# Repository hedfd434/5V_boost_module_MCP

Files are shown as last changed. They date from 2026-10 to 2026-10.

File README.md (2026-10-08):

# 5V converter evaluation board (MCP1640T-I/CHY)
this board allows user to get 5V power supply with maximum out current of 1A (limited by coil to 0.8A).
You can safely power your 5V devices controlled by MCU's or evaluation boards

<figure>
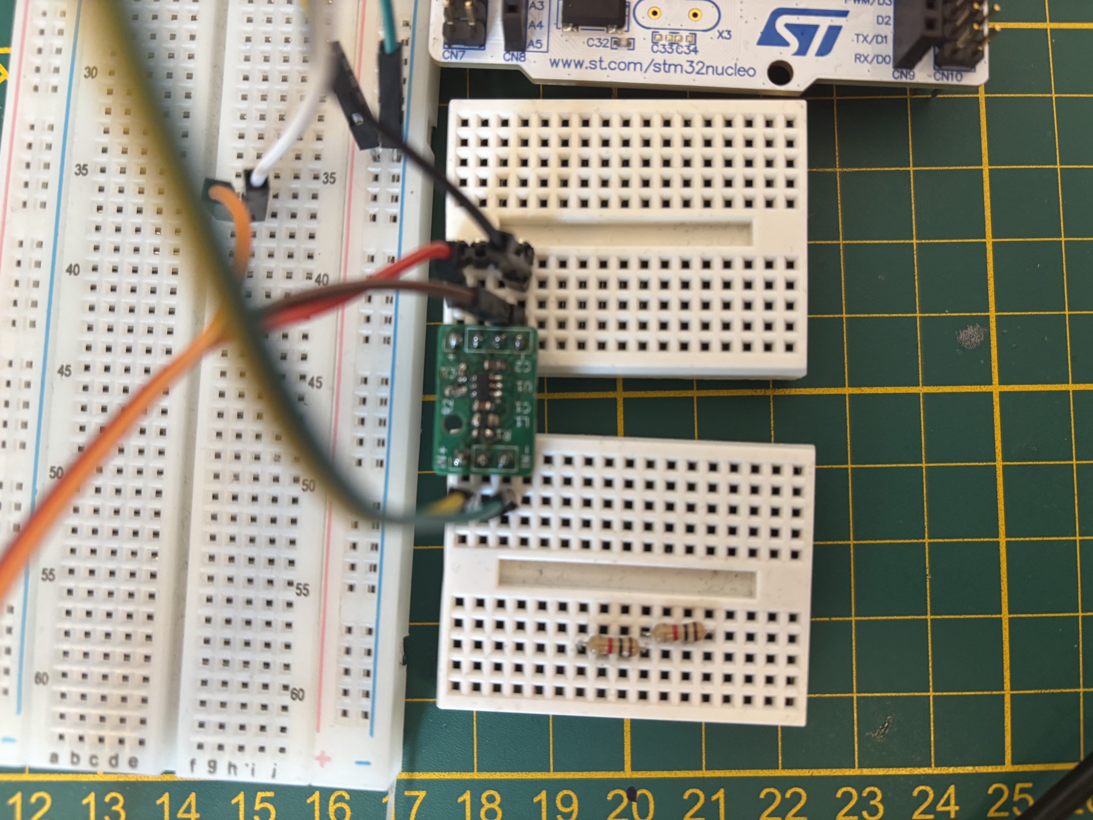
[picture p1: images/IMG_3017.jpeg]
  
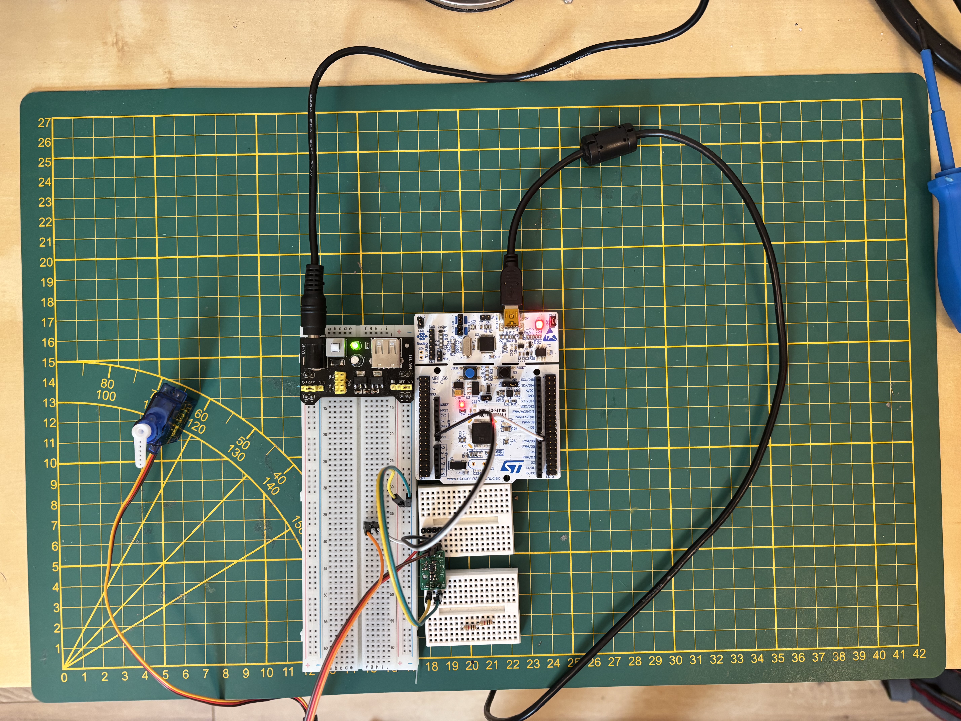
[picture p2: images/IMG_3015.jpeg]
    
  <figcaption>
    Image 1 and 2. Board in real usage power 5V servo
  </figcaption>
</figure>

## features
- DC to DC power conversion (boost)
- input voltage 3.0 to 4.2 V (possible change to range of 0.9 to 1.7V by replacing 309ohm resistor with 562ohm resistor)
- up to 95% efficiency in range of 10 - 100mA
- custom enabler: you can control on and off state by EN pin or permanently solder the 0ohm resistor.

<figure>
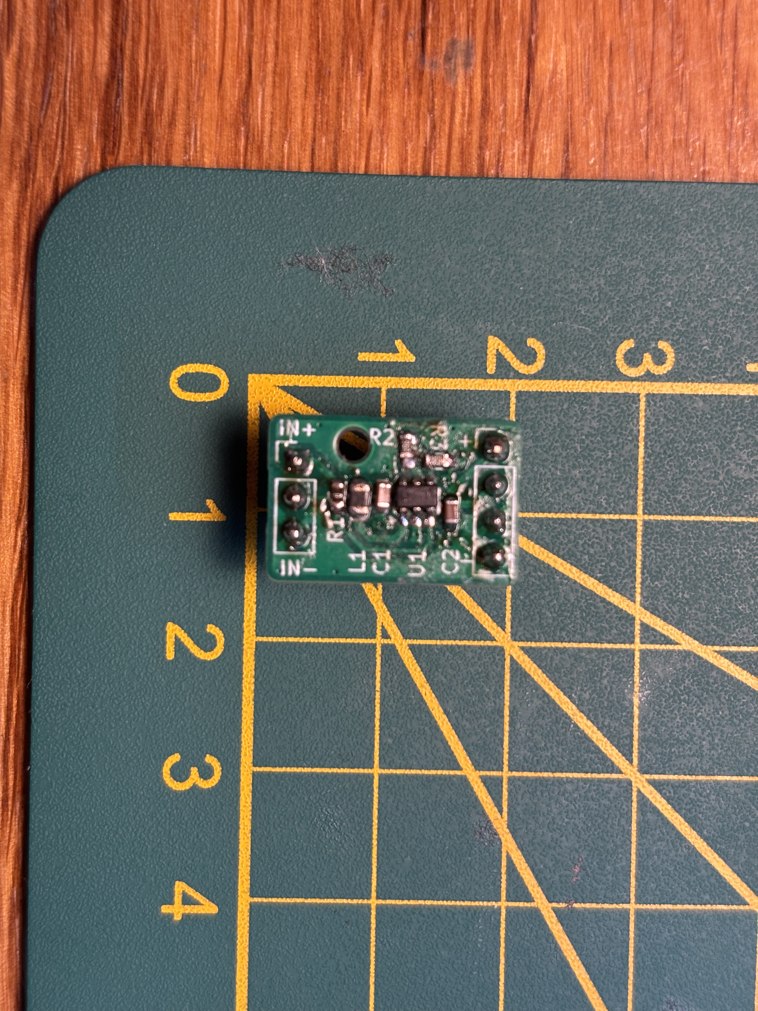
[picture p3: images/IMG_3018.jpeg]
  
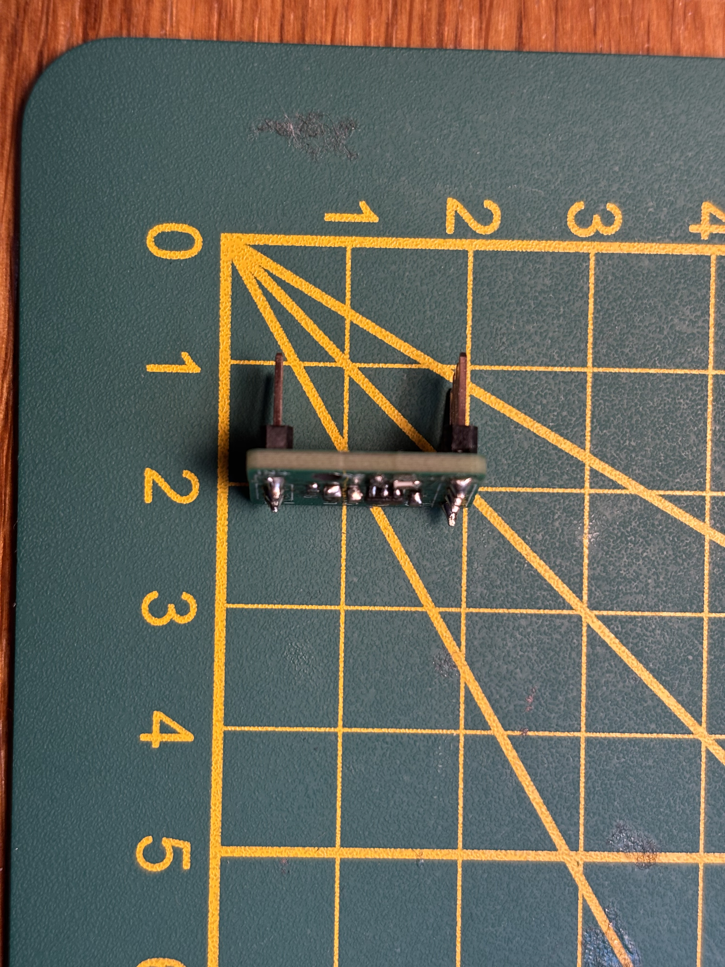
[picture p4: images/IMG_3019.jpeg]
    
  <figcaption>
    Image 3 and 4. Detailed view with real scale.
  </figcaption>
</figure>

## issues
- the GPIO pins are not alligned, it requires using 2 bread boards or custom cutouts in pcb.

## components used in the project
1. 5V chip MCP1640T-I/CHY
2. coil LQM21PN4R7MGRD
3. 10uF 0603 capacitor
4. 4.7uG 0603 capacitor
4. 0ohm 0603 resitor
5. 309ohm 0603 resistor
6. 976ohm 0603 resistor

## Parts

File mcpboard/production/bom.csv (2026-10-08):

Designator | Footprint | Quantity | Value | LCSC Part #
C1 | 0603 | 1 | 4.7uF
C2 | 0603 | 1 | 10uF
L1 | 0805 | 1 | 4.7uH
R1 | 0603 | 1 | 0ohm
R2 | 0603 | 1 | 976ohm
R3 | 0603 | 1 | 309ohm
U1 | SOT-23-6 | 1 | MCP1640T-I/CHY

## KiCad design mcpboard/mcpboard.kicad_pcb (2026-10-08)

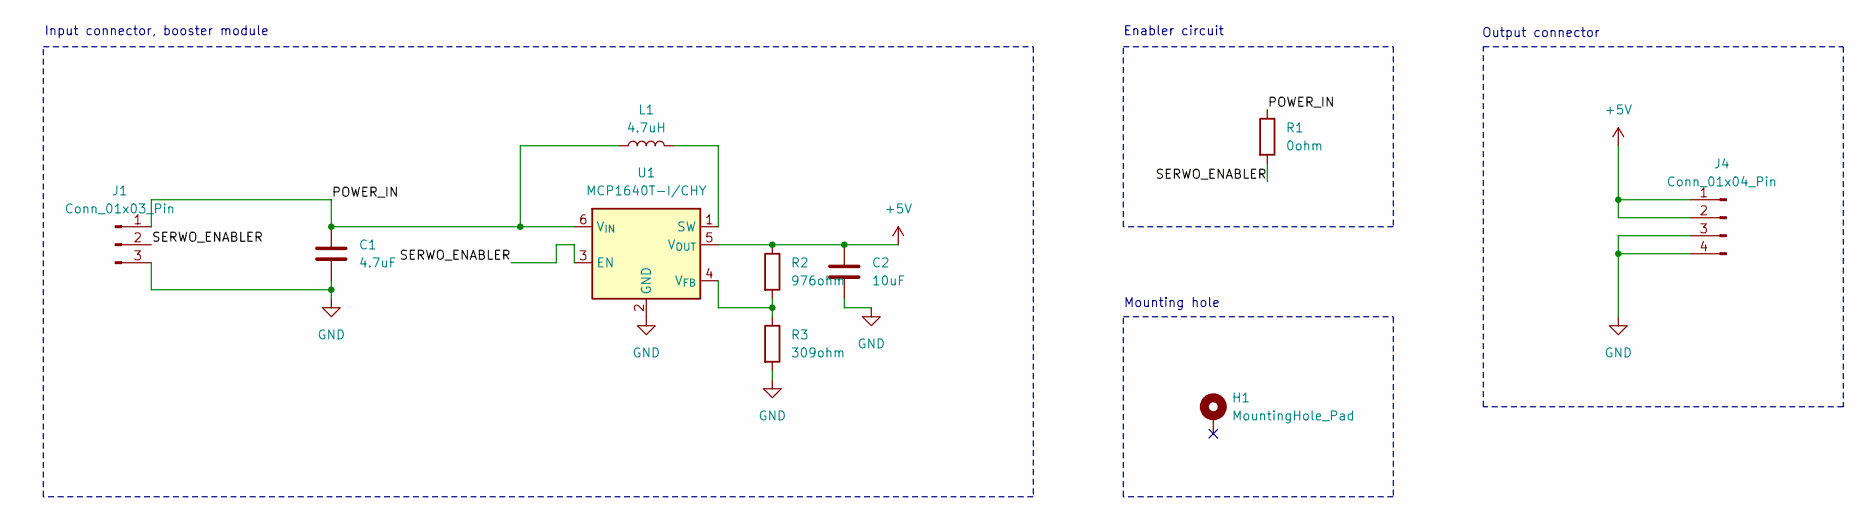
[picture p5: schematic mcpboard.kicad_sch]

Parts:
C1: 4.7uF; C_0603_1608Metric
C2: 10uF; C_0603_1608Metric
H1: MountingHole_Pad; MountingHole_2.2mm_M2
J1: Conn_01x03_Pin; PinHeader_1x03_P2.54mm_Vertical
J4: Conn_01x04_Pin; PinHeader_1x04_P2.54mm_Vertical
L1: 4.7uH; L_0805_2012Metric
R1: 0ohm; R_0603_1608Metric
R2: 976ohm; R_0603_1608Metric
R3: 309ohm; R_0603_1608Metric
U1: MCP1640T-I/CHY; SOT-23-6

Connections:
+5V: C2.1, J4.1, J4.2, R2.1, U1.5 (V_{OUT})
/POWER_IN: C1.1, J1.1, L1.1, R1.1, U1.6 (V_{IN})
/SERWO_ENABLER: J1.2, R1.2, U1.3 (EN)
GND: C1.2, C2.2, J1.3, J4.3, J4.4, R3.2, U1.2 (GND)
unnamed: L1.2, U1.1 (SW)
unnamed: R2.2, R3.1, U1.4 (V_{FB})

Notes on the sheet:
Mounting hole
Enabler circuit
Output connector
Input connector, booster module

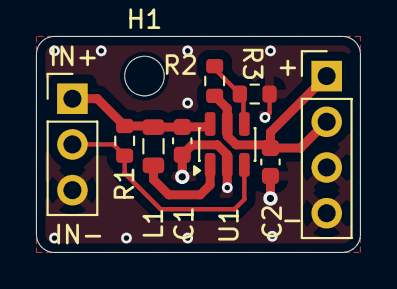
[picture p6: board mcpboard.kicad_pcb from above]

Board: 2 copper layers, 18.0 x 12.0 mm, 10 parts (0 on the bottom side), 6 nets.
